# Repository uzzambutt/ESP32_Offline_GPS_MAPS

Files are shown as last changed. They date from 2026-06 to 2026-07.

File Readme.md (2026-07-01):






# ESP32-S3 Offline GPS & Map Downloader
**Designed by Muhammad Uzzam Butt [(Contact)](mailto:uzzam@northernstudios.cc) // Made for [HC Offtrack YSWS](https://offtrack.hackclub.com/)**

A hardware-focused project developed for the Hack Club community. This repository contains the complete production-ready hardware design files for a custom 4-layer printed circuit board alongside a local web-based tile extraction tool optimized for generating offline map datasets.

## Hardware Overview

<p align="center">
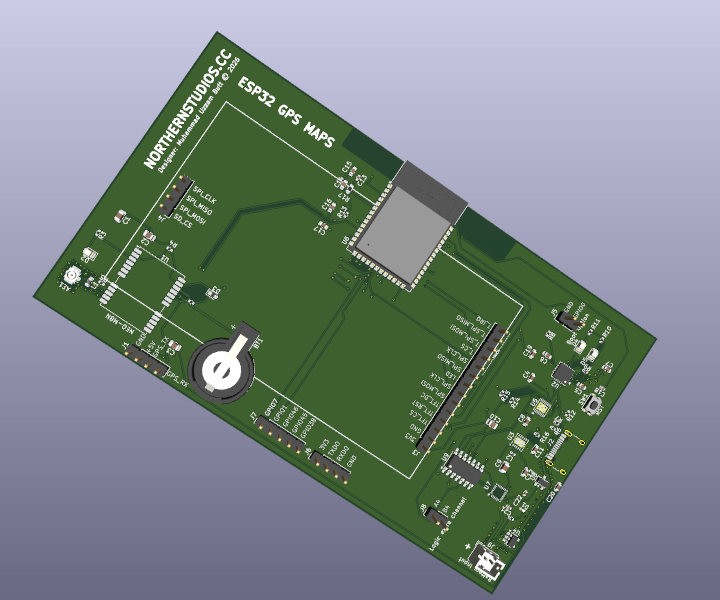
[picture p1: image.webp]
ESP32 GPS Maps 3D Render
  
</p>

The core of the project is an optimized 4-layer PCB using a multi-rail power distribution network and an isolated RF frontend designed to maintain signal integrity across high-speed digital and highly sensitive analog circuits.

### Circuit Architecture & Subsystems

* **Main Processor:** ESP32-S3-WROOM-1 module hosting the primary system buses, driving peripheral interfaces over SPI/I2C, and featuring an explicit copper keepout zone beneath the onboard PCB antenna to maximize wireless transmission efficiency.
* **GNSS / RF Frontend:** u-blox NEO-M8N positioning engine paired with an onboard U.FL connector for external active or passive antennas. The RF microstrip line is impedance-matched to 50 Ohms with a continuous, unbroken Layer 2 Ground reference plane beneath the entire path to suppress stray noise.
* **Inertial Navigation:** ICM-20948 9-axis IMU integrating a 3-axis gyroscope, 3-axis accelerometer, and 3-axis magnetometer for dead reckoning assistance.
* **Logic Level Translation:** TXS0104 4-bit bidirectional voltage-level translator handling safe high-speed communication between the 1.8V domain of the IMU and the 3.3V native logic level of the ESP32-S3.
* **Power Management Network (PMIC):**
  * **Charging Circuit:** MCP73871 LiPo charge management controller featuring dynamic power path management (System Load Sharing) to seamlessly transition power between USB/DC input and battery power.
  * **System Regulator (3.3V):** TPS63001 high-efficiency buck-boost converter supplying a stable 3.3V rail capable of absorbing the heavy transient current spikes during ESP32 Wi-Fi bursts.
  * **Sensor Regulator (1.8V):** AP2112K-1.8V low-dropout (LDO) linear regulator dedicated exclusively to isolating the sensitive analog components inside the IMU from digital switching noise.
  * **RTC Backup:** CR1220 coin cell retention circuit directly biasing the `V_BCKP` pin of the NEO-M8N to ensure warm/hot start capability and rapid orbital position locks.
* **User Interfaces & Storage:**
  * High-density micro-SD card slot attached via dedicated SPI lines for reading map tiles.
  * Custom TFT display expansion pin header broken out with hardware control lines (`CS`, `DC`, `RST`, `LED`).
  * Supplemental GPIO expansion breakouts (`GPIO7`, `GPIO2`, `GPIO46`, `GPIO45`, `GPIO38`) alongside a dedicated hardware UART interface (`TXD0`/`RXD0`) for diagnostics.

---

## Software: Map Tile Downloader

To support the offline hardware operation, a standalone map utility is provided to extract spatial tiles directly from web tile servers into an indexed directory structure ready for deployment to external storage media.

### Technical Stack
* **Frontend:** HTML, JavaScript, Leaflet.js rendering canvas, Leaflet.draw interface library configured with an orange, dashed polygon utility to visualize map coordinates.
* **Backend:** Python web server powered by the Flask micro-framework utilizing standard math libraries to translate mercator coordinates into standard XYZ tile grids.
* **Data Provider:** CartoDB Voyager raster tile api.

### Installation & Operation

1. Navigate to the code directory containing the script assets.
2. Install the necessary networking dependencies via pip:
   ```
   pip install flask requests

 3. Initialize the local Flask loop:
   ```
   python app.py
   
   ```
 4. Point a web browser to http://127.0.0.1:5000.
 5. Use the rectangle bounding tool to drag a perimeter over the geographical region you want to download.
 6. Trigger the download pipeline; files are compiled directly into the root folder under
    ```
    /downloaded_maps/{zoom}/{x}/{y}.png
    ```

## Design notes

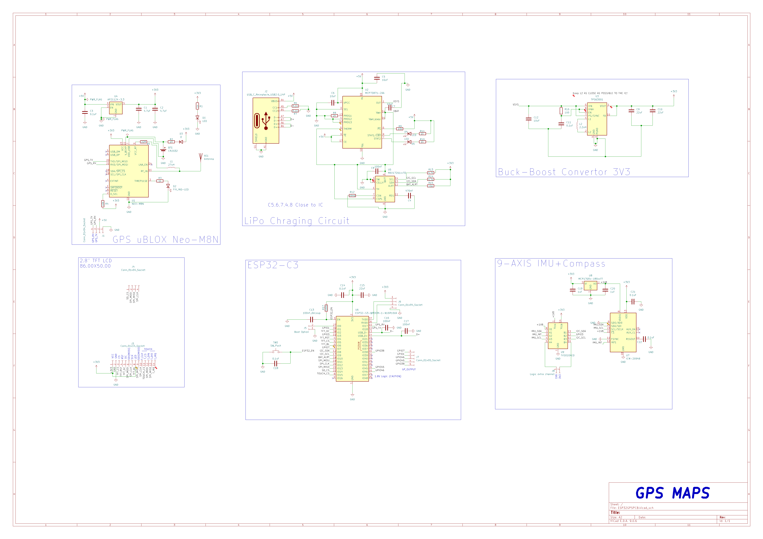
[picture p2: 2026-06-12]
ESP32GPSPCB/SCHEMATIC.png

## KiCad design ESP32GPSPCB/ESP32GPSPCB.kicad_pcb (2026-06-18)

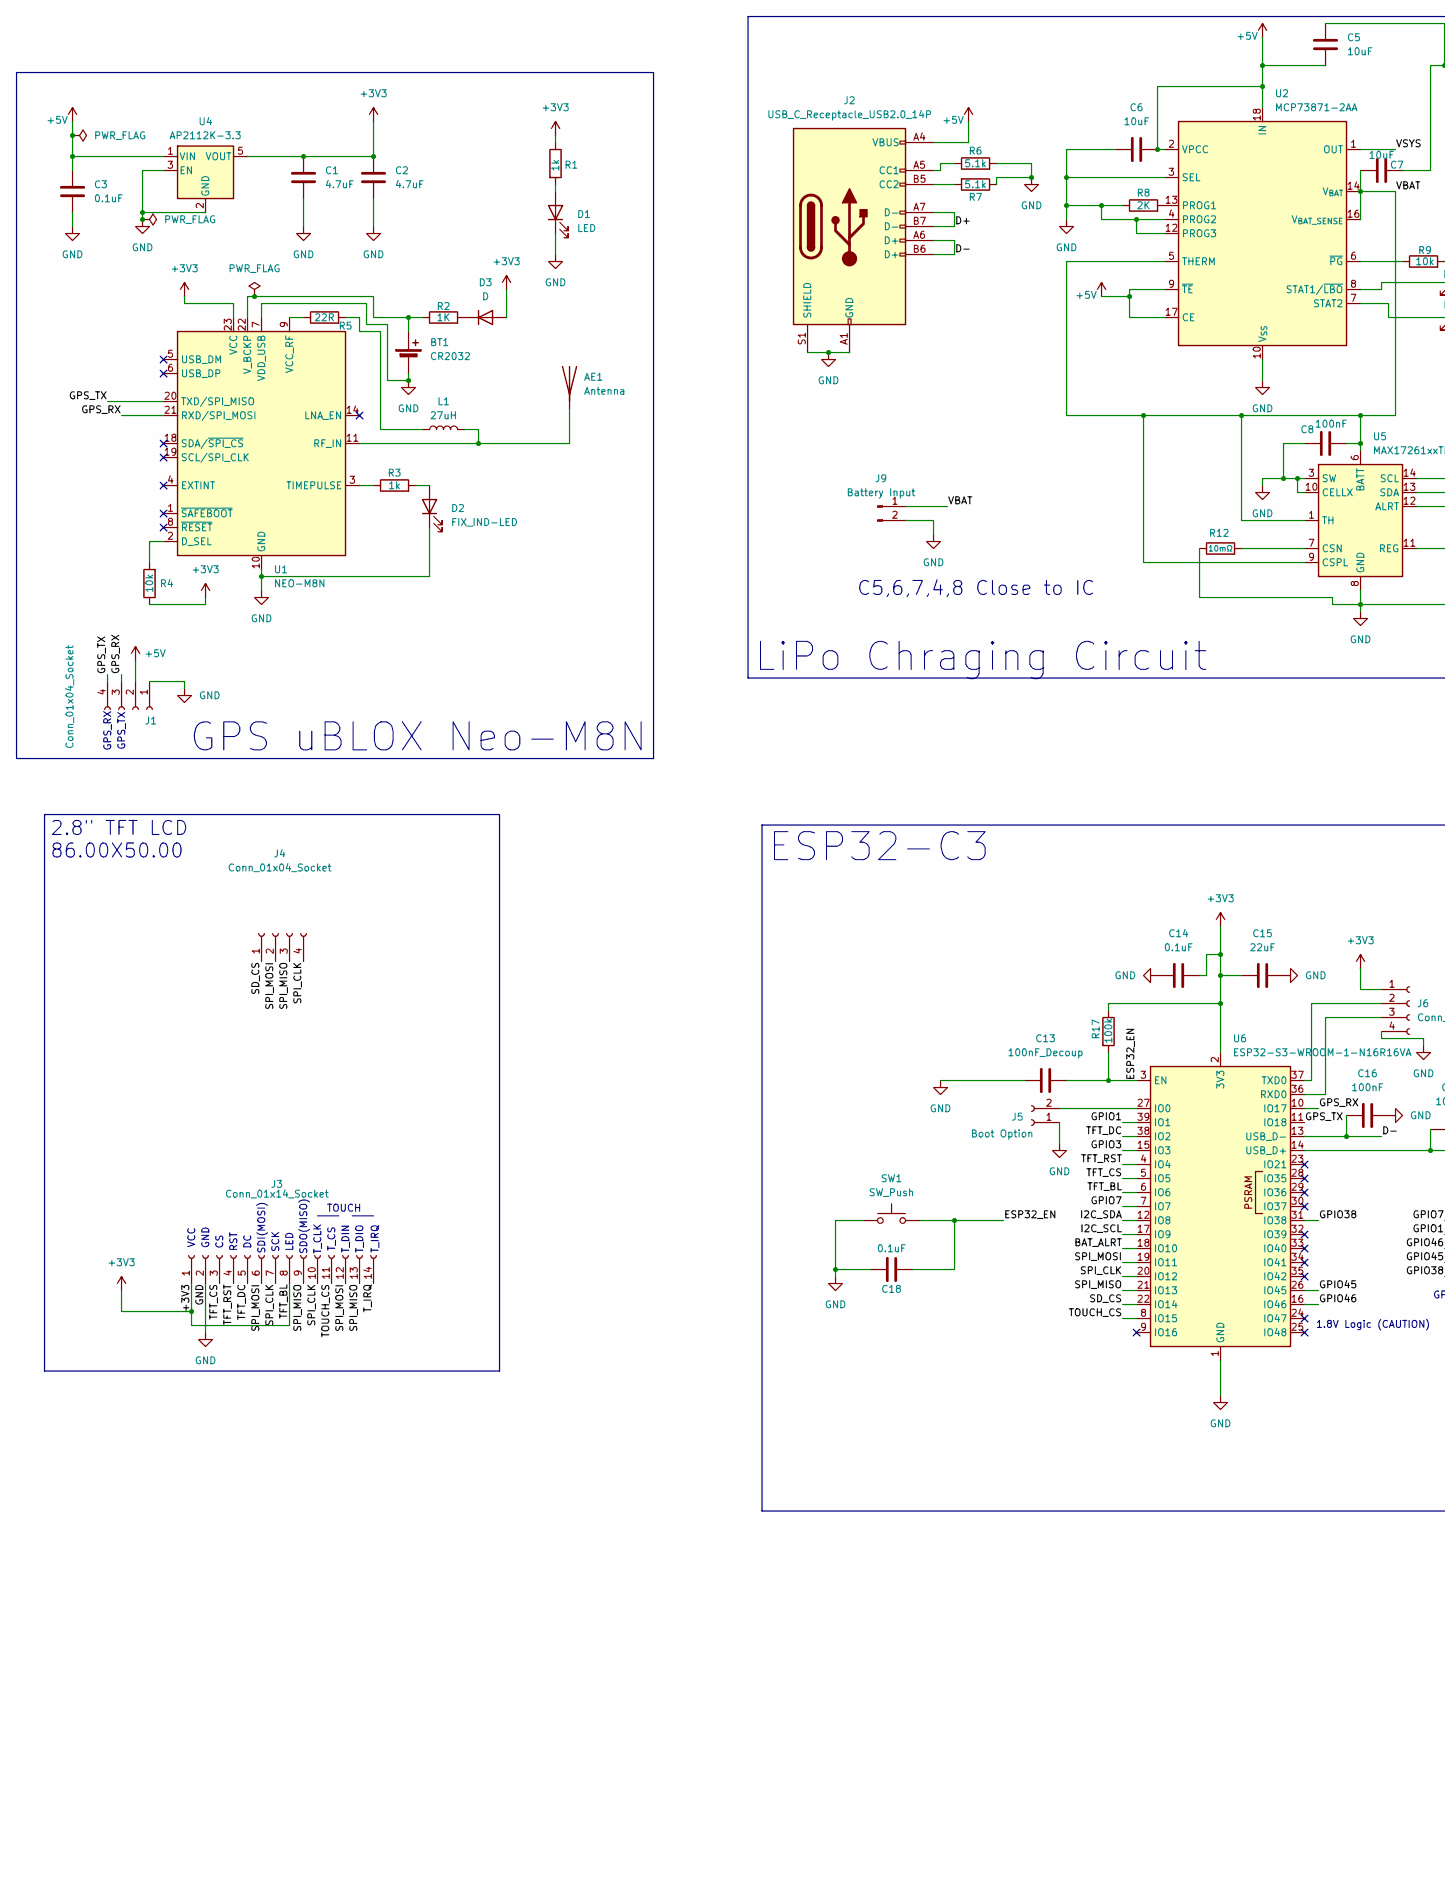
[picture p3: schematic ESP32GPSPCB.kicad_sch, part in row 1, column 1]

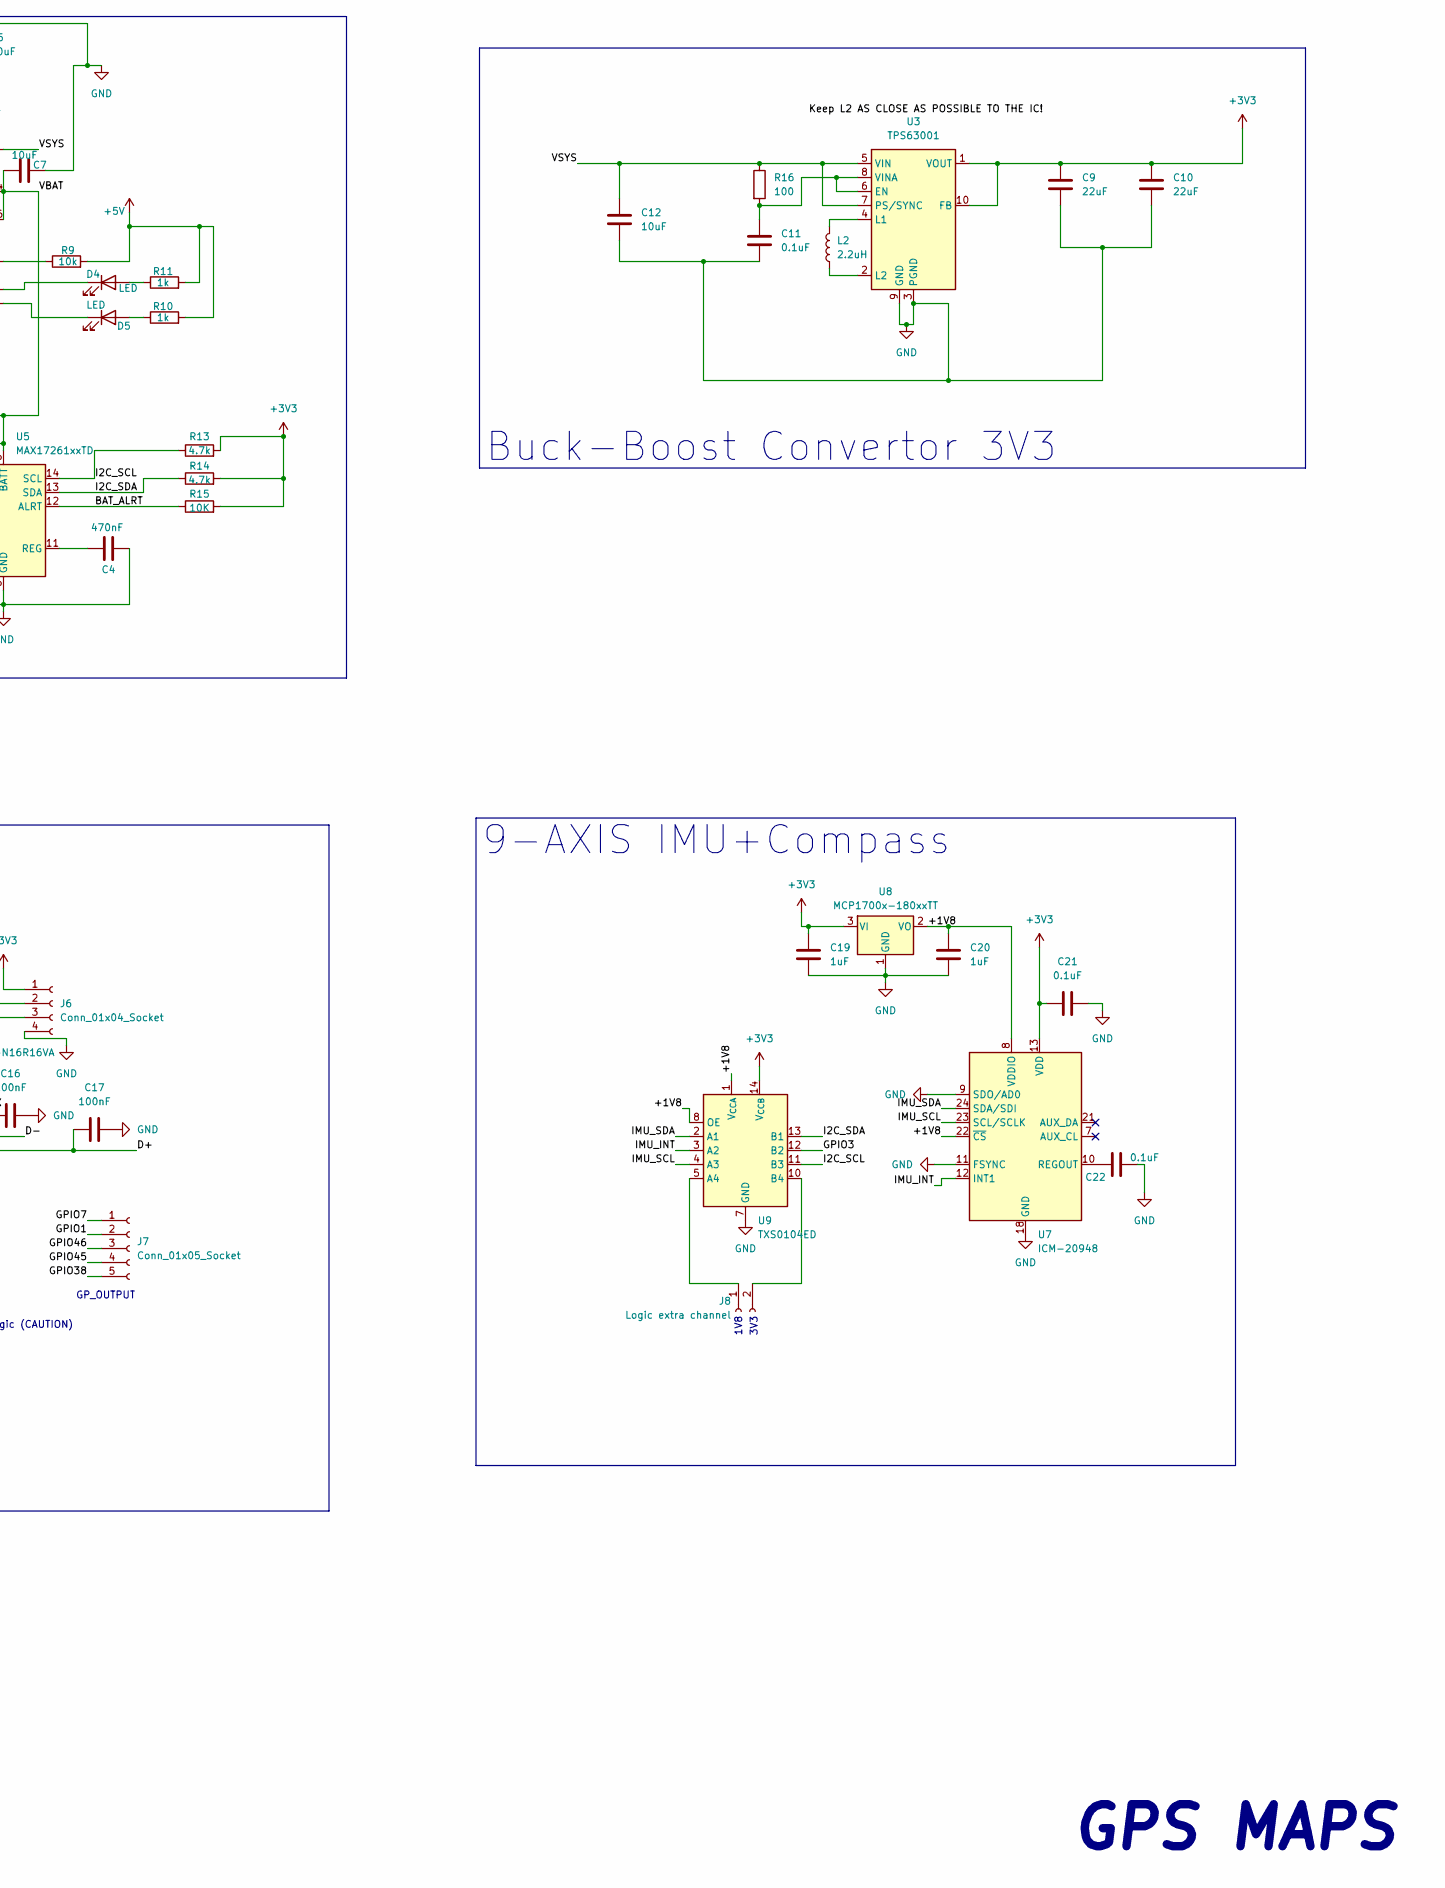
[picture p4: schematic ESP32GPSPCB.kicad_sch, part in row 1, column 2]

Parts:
AE1: Antenna; U.FL_Hirose_U.FL-R-SMT-1_Vertical
BT1: CR2032; BatteryHolder_Keystone_500
C1, C2: 4.7uF; C_0805_2012Metric
C3: 0.1uF; C_0805_2012Metric
C4: 470nF; C_0603_1608Metric
C5, C6, C7, C12: 10uF; C_0603_1608Metric
C8, C16, C17: 100nF; C_0603_1608Metric
C9, C10: 22uF; C_0805_2012Metric
C11, C14: 0.1uF; C_0603_1608Metric
C13: 100nF_Decoup; C_0402_1005Metric
C15: 22uF; C_0603_1608Metric
C18, C21, C22: 0.1uF; C_0402_1005Metric
C19, C20: 1uF; C_0603_1608Metric
D1: LED; LED_0402_1005Metric
D2: FIX_IND-LED; LED_0805_2012Metric
D3: D; D_0603_1608Metric
D4, D5: LED; LED_0805_2012Metric
J1, J4, J6: Conn_01x04_Socket; PinHeader_1x04_P2.54mm_Vertical
J2: USB_C_Receptacle_USB2.0_14P; USB_C_Receptacle_HCTL_HC-TYPE-C-16P-01A
J3: Conn_01x14_Socket; PinHeader_1x14_P2.54mm_Vertical
J5: Boot Option; PinHeader_1x02_P2.54mm_Vertical
J7: Conn_01x05_Socket; PinHeader_1x05_P2.54mm_Vertical
J8: Logic extra channel; PinHeader_1x02_P2.54mm_Vertical
J9: Battery Input; JST_PH_B2B-PH-K_1x02_P2.00mm_Vertical
L1: 27uH; L_0603_1608Metric
L2: 2.2uH; L_0402_1005Metric
R1, R3, R10, R11: 1k; R_0402_1005Metric
R2: 1K; R_0402_1005Metric
R4, R9: 10k; R_0402_1005Metric
R5: 22R; R_0402_1005Metric
R6, R7: 5.1k; R_0402_1005Metric
R8: 2K; R_0402_1005Metric
R12: 10mΩ; R_0402_1005Metric
R13, R14: 4.7k; R_0402_1005Metric
R15: 10K; R_0402_1005Metric
R16: 100; R_0402_1005Metric
R17: 100k; R_0603_1608Metric
SW1: SW_Push; SW_Push_1P1T_NO_CK_KMR2
U1: NEO-M8N; ublox_NEO
U2: MCP73871-2AA; QFN-20-1EP_4x4mm_P0.5mm_EP2.5x2.5mm
U3: TPS63001; Texas_DRC0010J_ThermalVias
U4: AP2112K-3.3; SOT-23-5
U5: MAX17261xxTD; TDFN-14-1EP_3x3mm_P0.4mm_EP1.78x2.35mm
U6: ESP32-S3-WROOM-1-N16R16VA; ESP32-S3-WROOM-1
U7: ICM-20948; InvenSense_QFN-24_3x3mm_P0.4mm
U8: MCP1700x-180xxTT; SOT-23
U9: TXS0104ED; SOIC-14_3.9x8.7mm_P1.27mm

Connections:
+3V3: C1.1, C2.1, C9.1, C10.1, C14.2, C15.1, C19.1, C21.1, D3.2 (A), J3.1, J3.8, J6.1, R1.1, R4.1, R13.2, R14.2, R15.2, R17.1, U1.23 (VCC), U3.1 (VOUT), U3.10 (FB), U4.5 (VOUT), U6.2 (3V3), U6.6 (IO6), U7.13 (VDD), U8.3 (VI), U9.14 (V_{CCB})
+5V: C3.1, C5.2, C6.2, J1.2, J2.A4 (VBUS), J2.A9 (VBUS), J2.B4 (VBUS), J2.B9 (VBUS), R9.2, R10.2, R11.2, U2.2 (VPCC), U2.9 (~TE), U2.17 (CE), U2.18 (IN), U2.19 (IN), U4.1 (VIN)
/+1V8: C20.1, U7.8 (VDDIO), U7.22 (~CS), U8.2 (VO), U9.1 (V_{CCA}), U9.8 (OE)
/BAT_ALRT: R15.1, U5.12 (ALRT), U6.18 (IO10)
/D+: C17.1, J2.A7 (D-), J2.B7 (D-), U6.14 (USB_D+)
/D-: C16.1, J2.A6 (D+), J2.B6 (D+), U6.13 (USB_D-)
/ESP32_EN: C13.2, C18.1, R17.2, SW1.2, U6.3 (EN)
/GPIO1: J7.2, U6.39 (IO1)
/GPIO3: U6.15 (IO3), U9.12 (B2)
/GPIO7: J7.1, U6.7 (IO7)
/GPIO38: J7.5, U6.31 (IO38)
/GPIO45: J7.4, U6.26 (IO45)
/GPIO46: J7.3, U6.16 (IO46)
/GPS_RX: J1.3, U1.21 (RXD/SPI_MOSI), U6.10 (IO17)
/GPS_TX: J1.4, U1.20 (TXD/SPI_MISO), U6.11 (IO18)
/I2C_SCL: R13.1, U5.14 (SCL), U6.17 (IO9), U9.11 (B3)
/I2C_SDA: R14.1, U5.13 (SDA), U6.12 (IO8), U9.13 (B1)
/IMU_INT: U7.12 (INT1), U9.3 (A2)
/IMU_SCL: U7.23 (SCL/SCLK), U9.4 (A3)
/IMU_SDA: U7.24 (SDA/SDI), U9.2 (A1)
/SD_CS: J4.1, U6.22 (IO14)
/SPI_CLK: J3.7, J3.10, J4.4, U6.20 (IO12)
/SPI_MISO: J3.9, J3.13, J4.3, U6.21 (IO13)
/SPI_MOSI: J3.6, J3.12, J4.2, U6.19 (IO11)
/TFT_CS: J3.3, U6.5 (IO5)
/TFT_DC: J3.5, U6.38 (IO2)
/TFT_RST: J3.4, U6.4 (IO4)
/TOUCH_CS: J3.11, U6.8 (IO15)
/T_IRQ: J3.14
/VBAT: C7.1, C8.2, J9.1, U2.5 (THERM), U2.14 (V_{BAT}), U2.15 (V_{BAT}), U2.16 (V_{BAT_SENSE}), U5.1 (TH), U5.6 (BATT), U5.9 (CSPL)
/VSYS: C12.1, R16.1, U2.1 (OUT), U2.20 (OUT), U3.5 (VIN), U3.7 (PS/SYNC)
GND: BT1.2 (-), C1.2, C2.2, C3.2, C4.2, C5.1, C6.1, C7.2, C8.1, C9.2, C10.2, C11.2, C12.2, C13.1, C14.1, C15.2, C16.2, C17.2, C18.2, C19.2, C20.2, C21.2, C22.2, D1.1 (K), D2.1 (K), J1.1, J2.A1 (GND), J2.A12 (GND), J2.B1 (GND), J2.B12 (GND), J2.S1 (SHIELD), J3.2, J5.1, J6.4, J9.2, R6.2, R7.1, R8.1, R12.1, SW1.1, U1.7 (VDD_USB), U1.10 (GND), U1.12 (GND), U1.13 (GND), U1.24 (GND), U2.3 (SEL), U2.4 (PROG2), U2.10 (V_{SS}), U2.11 (V_{SS}), U2.12 (PROG3), U2.21 (V_{SS}), U3.3 (PGND), U3.9 (GND), U3.11 (PGND), U4.2 (GND), U4.3 (EN), U5.3 (SW), U5.8 (GND), U5.10 (CELLX), U5.15 (GND), U6.1 (GND), U6.40 (GND), U6.41 (GND), U7.9 (SDO/AD0), U7.11 (FSYNC), U7.18 (GND), U7.20 (GND), U8.1 (GND), U9.7 (GND)
unnamed: AE1.1 (A), L1.2, U1.11 (RF_IN)
unnamed: BT1.1 (+), R2.1, U1.22 (V_BCKP)
unnamed: D1.2 (A), R1.2
unnamed: D2.2 (A), R3.2
unnamed: D3.1 (K), R2.2
unnamed: D4.2 (A), R11.1
unnamed: D4.1 (K), U2.8 (STAT1/~LBO)
unnamed: D5.2 (A), R10.1
unnamed: D5.1 (K), U2.7 (STAT2)
unnamed: J2.A5 (CC1), R6.1
unnamed: J2.B5 (CC2), R7.2
unnamed: J5.2, U6.27 (IO0)
unnamed: J6.2, U6.37 (TXD0)
unnamed: J6.3, U6.36 (RXD0)
unnamed: J8.1, U9.5 (A4)
unnamed: J8.2, U9.10 (B4)
unnamed: L1.1, R5.2
unnamed: R4.2, U1.2 (D_SEL)
unnamed: R3.1, U1.3 (TIMEPULSE)
unnamed: R5.1, U1.9 (VCC_RF)
unnamed: R8.2, U2.13 (PROG1)
unnamed: R9.1, U2.6 (~PG)
unnamed: C11.1, R16.2, U3.6 (EN), U3.8 (VINA)
unnamed: L2.2, U3.4 (L1)
unnamed: L2.1, U3.2 (L2)
unnamed: R12.2, U5.7 (CSN)
unnamed: C4.1, U5.11 (REG)
unnamed: C22.1, U7.10 (REGOUT)

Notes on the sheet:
TOUCH
3V3
GP_OUTPUT
T_IRQ
RST
T_DIO
T_DIN
VCC
C5,6,7,4,8 Close to IC
SDI(MOSI)
GPS_TX
1V8
SDO(MISO)
LED
GPS MAPS
GND
SCK
GPS_RX
T_CS
1.8V Logic (CAUTION)
T_CLK
Buck-Boost Convertor 3V3
ESP32-C3
2.8" TFT LCD 86.00X50.00
9-AXIS IMU+Compass
LiPo Chraging Circuit
GPS uBLOX Neo-M8N

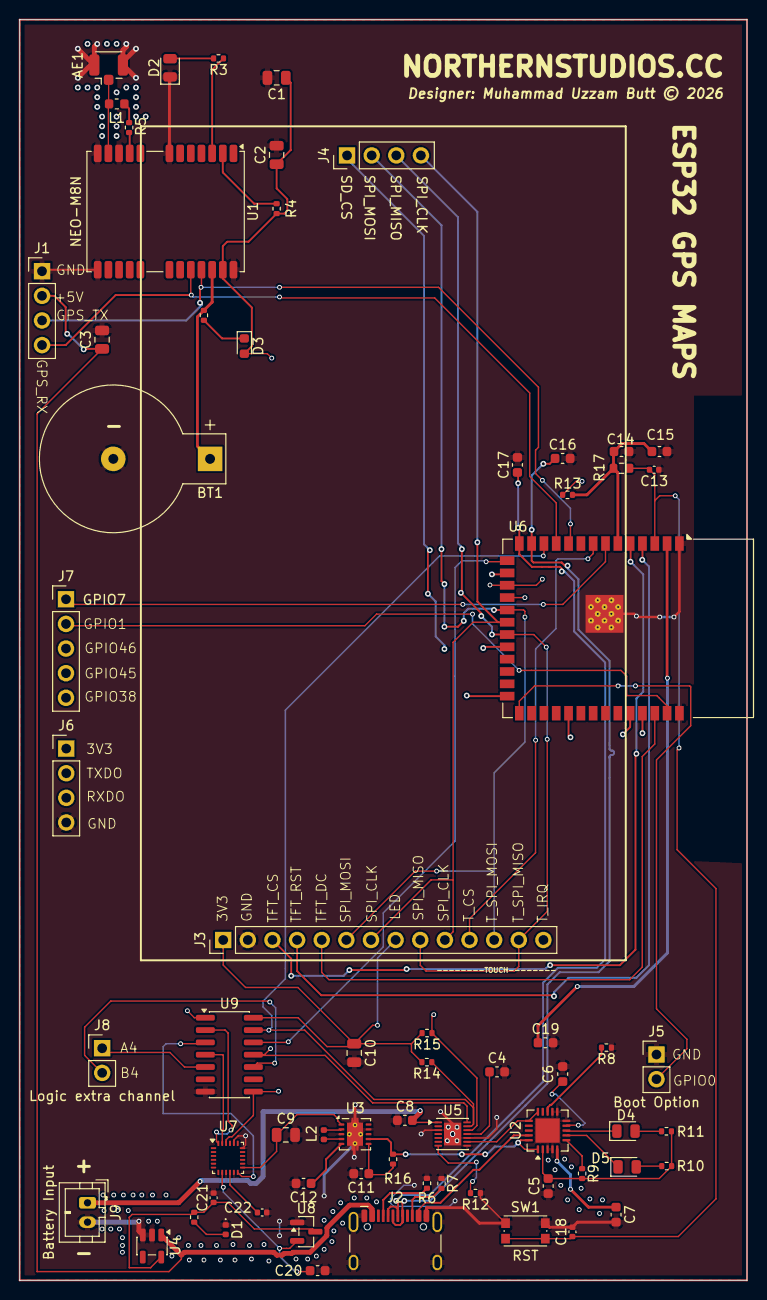
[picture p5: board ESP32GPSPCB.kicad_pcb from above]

Board: 4 copper layers, 75.0 x 130.0 mm, 67 parts (0 on the bottom side), 59 nets.

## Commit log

2026-06-10 completed GPS and BUCK-BOOST CONV
    [ESP32GPSPCB.kicad_sch]
2026-06-11 fixed some stuff
    [ESP32GPSPCB.kicad_sch]
2026-06-11 started working on the ESP32 chip
    [ESP32GPSPCB.kicad_sch]
2026-06-12 completed ESP32 logic, wired up some net labels and stuff
    [ESP32GPSPCB.kicad_sch]
2026-06-12 completed IMU circuit, added logic level convertor
    [ESP32GPSPCB.kicad_sch]
2026-06-12 schematic added, IMU finished, ERC RAN ERRORS FIXED
    [ESP32GPSPCB.kicad_sch]
2026-06-16 placed all components
    [ESP32GPSPCB.kicad_pcb, ESP32GPSPCB.kicad_sch]
2026-06-16 routed some of the parts
    [ESP32GPSPCB.kicad_pcb]
2026-06-18 Routed all traces and poured copper planes, GND, +1V8, VSYS, +3V3
    [ESP32GPSPCB.kicad_pcb]
2026-06-18 added designs and silkscreens
    [ESP32GPSPCB.kicad_pcb]
2026-06-18 power plane fixes
    [ESP32GPSPCB.kicad_pcb]

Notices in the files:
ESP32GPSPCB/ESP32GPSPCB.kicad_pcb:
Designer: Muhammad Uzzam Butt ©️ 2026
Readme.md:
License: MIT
